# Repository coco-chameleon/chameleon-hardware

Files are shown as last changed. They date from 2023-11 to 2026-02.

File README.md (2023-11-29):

# CoCo Chameleon

The CoCo Chameleon is a cartridge for the Tandy TRS-80 Color Computer
line of home computers from the 1980s which emulates other cartridges.
It supports all three versions of the CoCo and should be able to
replicate the computer-facing behavior of nearly any other cartridge.

The primary aim of the project is to emulate ROM cartridges and all
of the common floppy and hard disk controller cartridges from image
files stored on a MicroSD card.

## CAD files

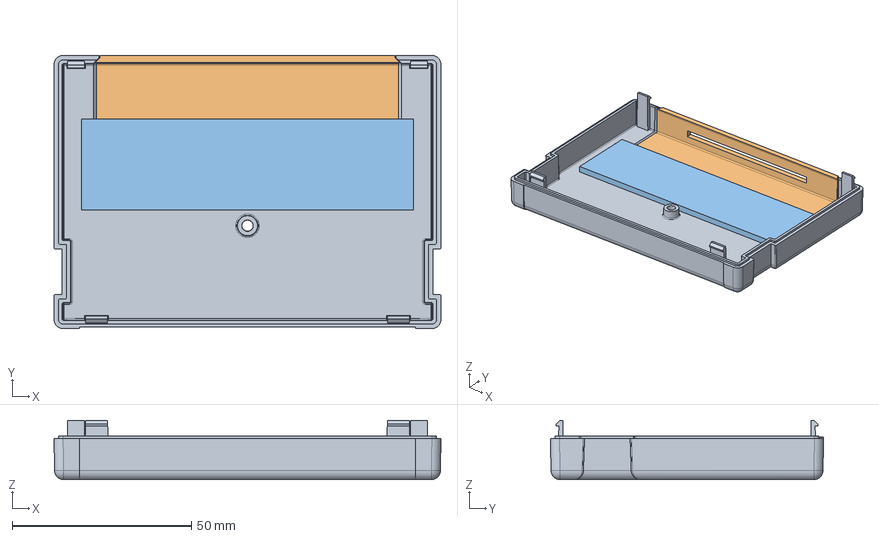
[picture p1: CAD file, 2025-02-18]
enclosure/ChameleonCase.FCStd
107.9 x 76.2 x 16.5 mm
P021_BottomShell
P022_Shutter
P023_ShutterBridge

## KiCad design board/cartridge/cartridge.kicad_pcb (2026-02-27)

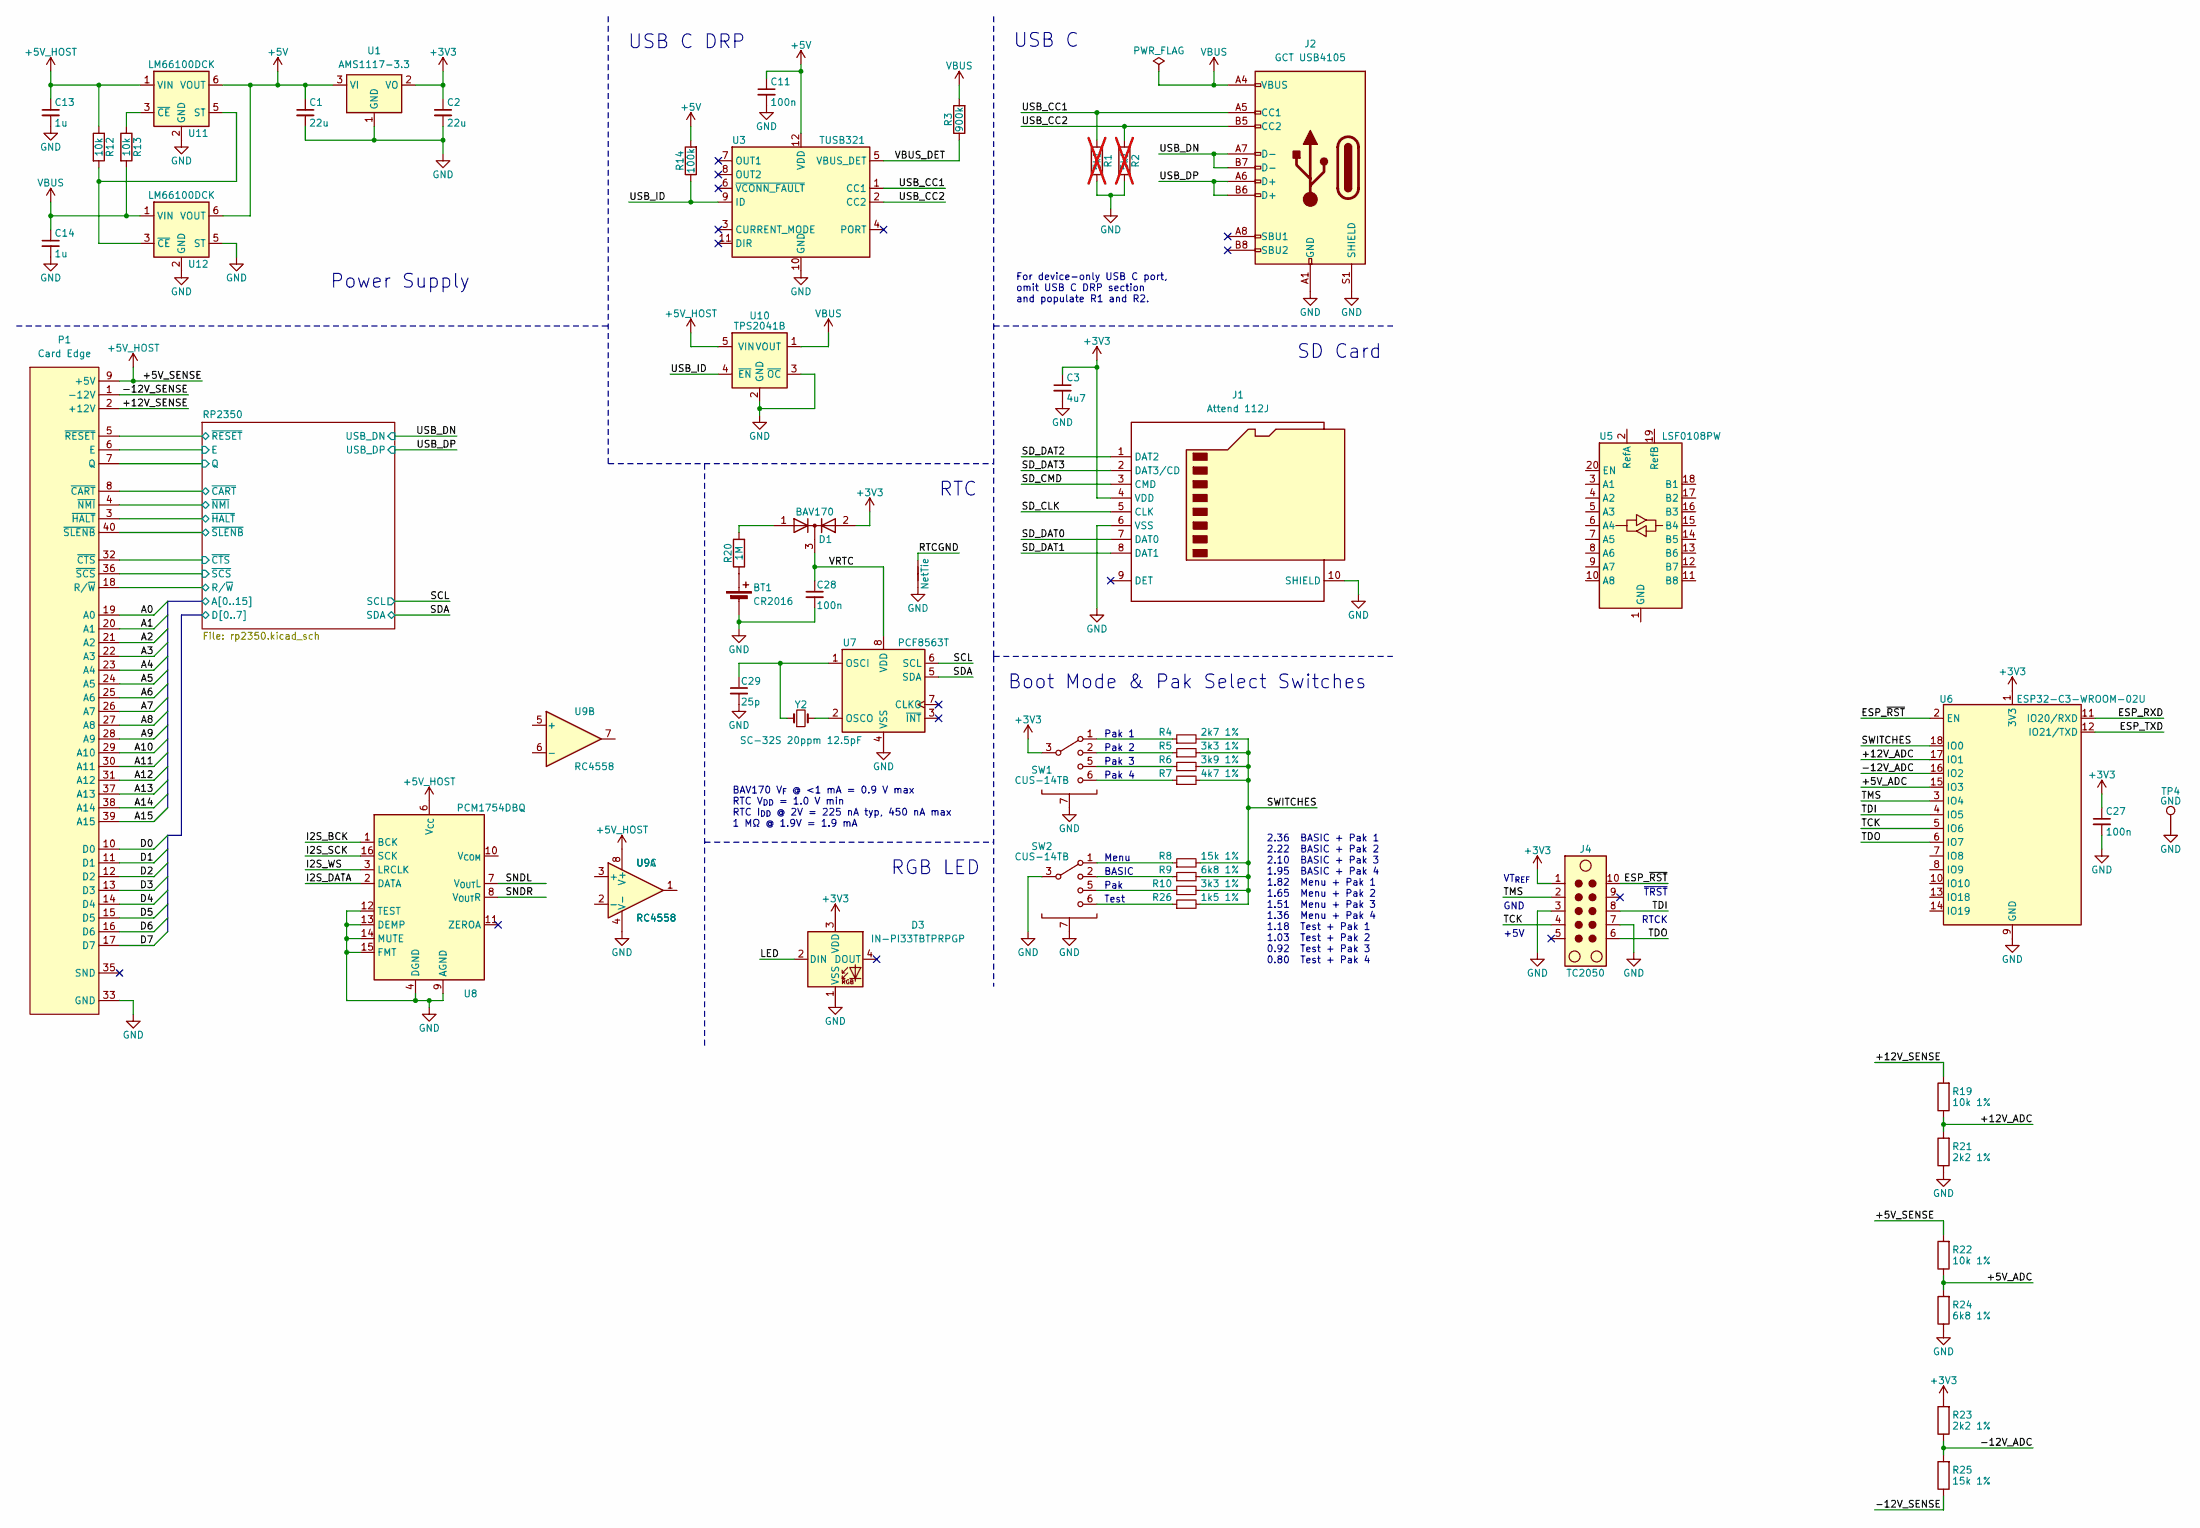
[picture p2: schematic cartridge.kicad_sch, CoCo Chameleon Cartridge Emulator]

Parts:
BT1: CR2016; BatteryHolder_Keystone_3026_1x2016
C1, C2: 22u; C_1206_3216Metric
C3: 4u7; C_0603_1608Metric
C11, C27, C28: 100n; C_0603_1608Metric
C13, C14: 1u; C_0603_1608Metric
C29: 25p; C_0603_1608Metric
D1: BAV170; SOT-23; LCSC C109309
D3: IN-PI33TBTPRPGP; LED_1414_3535Metric; LCSC C5259062
J1: Attend 112J; Attend_112J; LCSC C393941
J2: GCT USB4105; GCT_USB4105; LCSC C2894898
J4: TC2050; Tag-Connect_TC2050-IDC-NL_2x05_P1.27mm_Vertical
NT1: NetTie
P1: Card Edge; CoCo_Cart
R1, R2: 5k1; R_0603_1608Metric; not fitted
R3: 900k; R_0603_1608Metric
R4: 2k7 1%; R_0402_1005Metric
R5, R10: 3k3 1%; R_0402_1005Metric
R6: 3k9 1%; R_0402_1005Metric
R7: 4k7 1%; R_0402_1005Metric
R8, R25: 15k 1%; R_0402_1005Metric
R9, R24: 6k8 1%; R_0402_1005Metric
R12, R13: 10k; R_0603_1608Metric
R14: 100k; R_0603_1608Metric
R19, R22: 10k 1%; R_0402_1005Metric
R20: 1M; R_0603_1608Metric
R21, R23: 2k2 1%; R_0402_1005Metric
R26: 1k5 1%; R_0402_1005Metric
SW1, SW2: CUS-14TB; Nidec_CUS-14TB; LCSC C145846
TP4: GND; TestPoint_Pad_4.0x4.0mm
U1: AMS1117-3.3; SOT-223-3_TabPin2; LCSC C6186
U3: TUSB321; Texas_X2QFN-12_1.6x1.6mm_P0.4mm; LCSC C139392
U5: LSF0108PW; TSSOP-20_4.4x6.5mm_P0.65mm; LCSC C190219
U6: ESP32-C3-WROOM-02U
U7: PCF8563T; SOIC-8_3.9x4.9mm_P1.27mm; LCSC C7440
U8: PCM1754DBQ; SSOP-16_3.9x4.9mm_P0.635mm
U9: RC4558; SOIC-8_3.9x4.9mm_P1.27mm
U10: TPS2041B; SOT-23-5; LCSC C51386
U11, U12: LM66100DCK; SOT-363_SC-70-6; LCSC C2869734
Y2: SC-32S 20ppm 12.5pF; Crystal_SMD_3215-2Pin_3.2x1.5mm; LCSC C97606

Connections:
+3V3: C2.1, C3.1, C27.1, D1.2 (A), D3.3 (VDD), J1.4 (VDD), J4.1, R23.2, SW1.3 (COM), SW1.4 (COM), U1.2 (VO), U6.1 (3V3); also elsewhere on the board
+5V: C1.1, C11.1, R14.2, U1.3 (VI), U3.12 (VDD), U11.6 (VOUT), U12.6 (VOUT)
+5V_HOST: C13.1, P1.9 (+5V), R12.1, R22.2, U8.6 (V_{CC}), U9.8 (V+), U10.5 (VIN), U11.1 (VIN)
/+5V_ADC: R22.1, R24.2, U6.15 (IO3)
/+12V_ADC: R19.1, R21.2, U6.17 (IO1)
/+12V_SENSE: P1.2 (+12V), R19.2
/-12V_ADC: R23.1, R25.2, U6.16 (IO2)
/-12V_SENSE: P1.1 (-12V), R25.1
/ESP_RXD: U6.11 (IO20/RXD)
/ESP_TXD: U6.12 (IO21/TXD)
/ESP_~RST: J4.10, U6.2 (EN)
/I2S_BCK: U8.1 (BCK)
/I2S_DATA: U8.2 (DATA)
/I2S_SCK: U8.16 (SCK)
/I2S_WS: U8.3 (LRCLK)
/LED: D3.2 (DIN)
/RP2350/A0: P1.19 (A0); also elsewhere on the board
/RP2350/A1: P1.20 (A1); also elsewhere on the board
/RP2350/A2: P1.21 (A2); also elsewhere on the board
/RP2350/A3: P1.22 (A3); also elsewhere on the board
/RP2350/A4: P1.23 (A4); also elsewhere on the board
/RP2350/A5: P1.24 (A5); also elsewhere on the board
/RP2350/A6: P1.25 (A6); also elsewhere on the board
/RP2350/A7: P1.26 (A7); also elsewhere on the board
/RP2350/A8: P1.27 (A8); also elsewhere on the board
/RP2350/A9: P1.28 (A9); also elsewhere on the board
/RP2350/A10: P1.29 (A10); also elsewhere on the board
/RP2350/A11: P1.30 (A11); also elsewhere on the board
/RP2350/A12: P1.31 (A12); also elsewhere on the board
/RP2350/A13: P1.37 (A13); also elsewhere on the board
/RP2350/A14: P1.38 (A14); also elsewhere on the board
/RP2350/A15: P1.39 (A15); also elsewhere on the board
/RP2350/D0: P1.10 (D0); also elsewhere on the board
/RP2350/D1: P1.11 (D1); also elsewhere on the board
/RP2350/D2: P1.12 (D2); also elsewhere on the board
/RP2350/D3: P1.13 (D3); also elsewhere on the board
/RP2350/D4: P1.14 (D4); also elsewhere on the board
/RP2350/D5: P1.15 (D5); also elsewhere on the board
/RP2350/D6: P1.16 (D6); also elsewhere on the board
/RP2350/D7: P1.17 (D7); also elsewhere on the board
/RP2350/E: P1.6 (E); also elsewhere on the board
/RP2350/Q: P1.7 (Q); also elsewhere on the board
/RP2350/R/~W: P1.18 (R/~W); also elsewhere on the board
/RP2350/~CART: P1.8 (~CART); also elsewhere on the board
/RP2350/~CTS: P1.32 (~CTS); also elsewhere on the board
/RP2350/~HALT: P1.3 (~HALT); also elsewhere on the board
/RP2350/~NMI: P1.4 (~NMI); also elsewhere on the board
/RP2350/~RESET: P1.5 (~RESET); also elsewhere on the board
/RP2350/~SCS: P1.36 (~SCS); also elsewhere on the board
/RP2350/~SLENB: P1.40 (~SLENB); also elsewhere on the board
/SCL: U7.6 (SCL); also elsewhere on the board
/SDA: U7.5 (SDA); also elsewhere on the board
/SD_CLK: J1.5 (CLK)
/SD_CMD: J1.3 (CMD)
/SD_DAT0: J1.7 (DAT0)
/SD_DAT1: J1.8 (DAT1)
/SD_DAT2: J1.1 (DAT2)
/SD_DAT3: J1.2 (DAT3/CD)
/SNDL: U8.7 (V_{OUT}L)
/SNDR: U8.8 (V_{OUT}R)
/SWITCHES: R4.2, R5.2, R6.2, R7.2, R8.2, R9.2, R10.2, R26.2, U6.18 (IO0)
/TCK: J4.4, U6.5 (IO6)
/TDI: J4.8, U6.4 (IO5)
/TDO: J4.6, U6.6 (IO7)
/TMS: J4.2, U6.3 (IO4)
/USB_CC1: J2.A5 (CC1), R1.1, U3.1 (CC1)
/USB_CC2: J2.B5 (CC2), R2.1, U3.2 (CC2)
/USB_DN: J2.A7 (D-), J2.B7 (D-); also elsewhere on the board
/USB_DP: J2.A6 (D+), J2.B6 (D+); also elsewhere on the board
/USB_ID: R14.1, U3.9 (ID), U10.4 (~EN)
/VBUS_DET: R3.1, U3.5 (VBUS_DET)
/VRTC: C28.1, D1.3 (K), U7.8 (VDD)
GND: BT1.2 (-), C1.2, C2.2, C3.2, C11.2, C13.2, C14.2, C27.2, C28.2, C29.2, D3.1 (VSS), J1.6 (VSS), J1.10 (SHIELD), J2.A1 (GND), J2.A12 (GND), J2.B1 (GND), J2.B12 (GND), J2.S1 (SHIELD), J4.3, J4.7, NT1.1, P1.33 (GND), P1.34 (GND), R1.2, R2.2, R21.1, R24.1, SW1.7 (SHIELD), SW2.3 (COM), SW2.4 (COM), SW2.7 (SHIELD), TP4.1, U1.1 (GND), U3.10 (GND), U6.9 (GND), U6.19 (GND), U7.4 (VSS), U8.4 (DGND), U8.9 (AGND), U8.12 (TEST), U8.13 (DEMP), U8.14 (MUTE), U8.15 (FMT), U9.4 (V-), U10.2 (GND), U10.3 (~OC), U11.2 (GND), U12.2 (GND), U12.5 (ST); also elsewhere on the board
unnamed: BT1.1 (+), R20.1
unnamed: D1.1 (A), R20.2
unnamed: R4.1, SW1.1
unnamed: R5.1, SW1.2
unnamed: R8.1, SW2.1
unnamed: R9.1, SW2.2
unnamed: R6.1, SW1.5 (3)
unnamed: R7.1, SW1.6 (4)
unnamed: R10.1, SW2.5 (3)
unnamed: R26.1, SW2.6 (4)
unnamed: C29.1, U7.1 (OSCI), Y2.1
unnamed: U7.2 (OSCO), Y2.2
unnamed: R12.2, U11.5 (ST), U12.3 (~CE)
unnamed: R13.1, U11.3 (~CE)
VBUS: C14.1, J2.A4 (VBUS), J2.A9 (VBUS), J2.B4 (VBUS), J2.B9 (VBUS), R3.2, R13.2, U10.1 (VOUT), U12.1 (VIN)

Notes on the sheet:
SD Card
For device-only USB C port, omit USB C DRP section and populate R1 and R2.
Pak
Pak 3
BASIC
RTC
RTCK
2.36 BASIC + Pak 1 2.22 BASIC + Pak 2 2.10 BASIC + Pak 3 1.95 BASIC + Pak 4 1.82 Menu + Pak 1 1.65 Menu + Pak 2 1.51 Menu + Pak 3 1.36 Menu + Pak 4 1.18 Test + Pak 1 1.03 Test + Pak 2 0.92 Test + Pak 3 0.80 Test + Pak 4
Boot Mode & Pak Select Switches
VT_{REF}
+5V
Power Supply
BAV170 V_{F} @ <1 mA = 0.9 V max RTC V_{DD} = 1.0 V min RTC I_{DD} @ 2V = 225 nA typ, 450 nA max 1 MΩ @ 1.9V = 1.9 mA
USB C DRP
Test
~{TRST}
GND
Pak 4
Pak 1
RGB LED
Menu
Pak 2
USB C

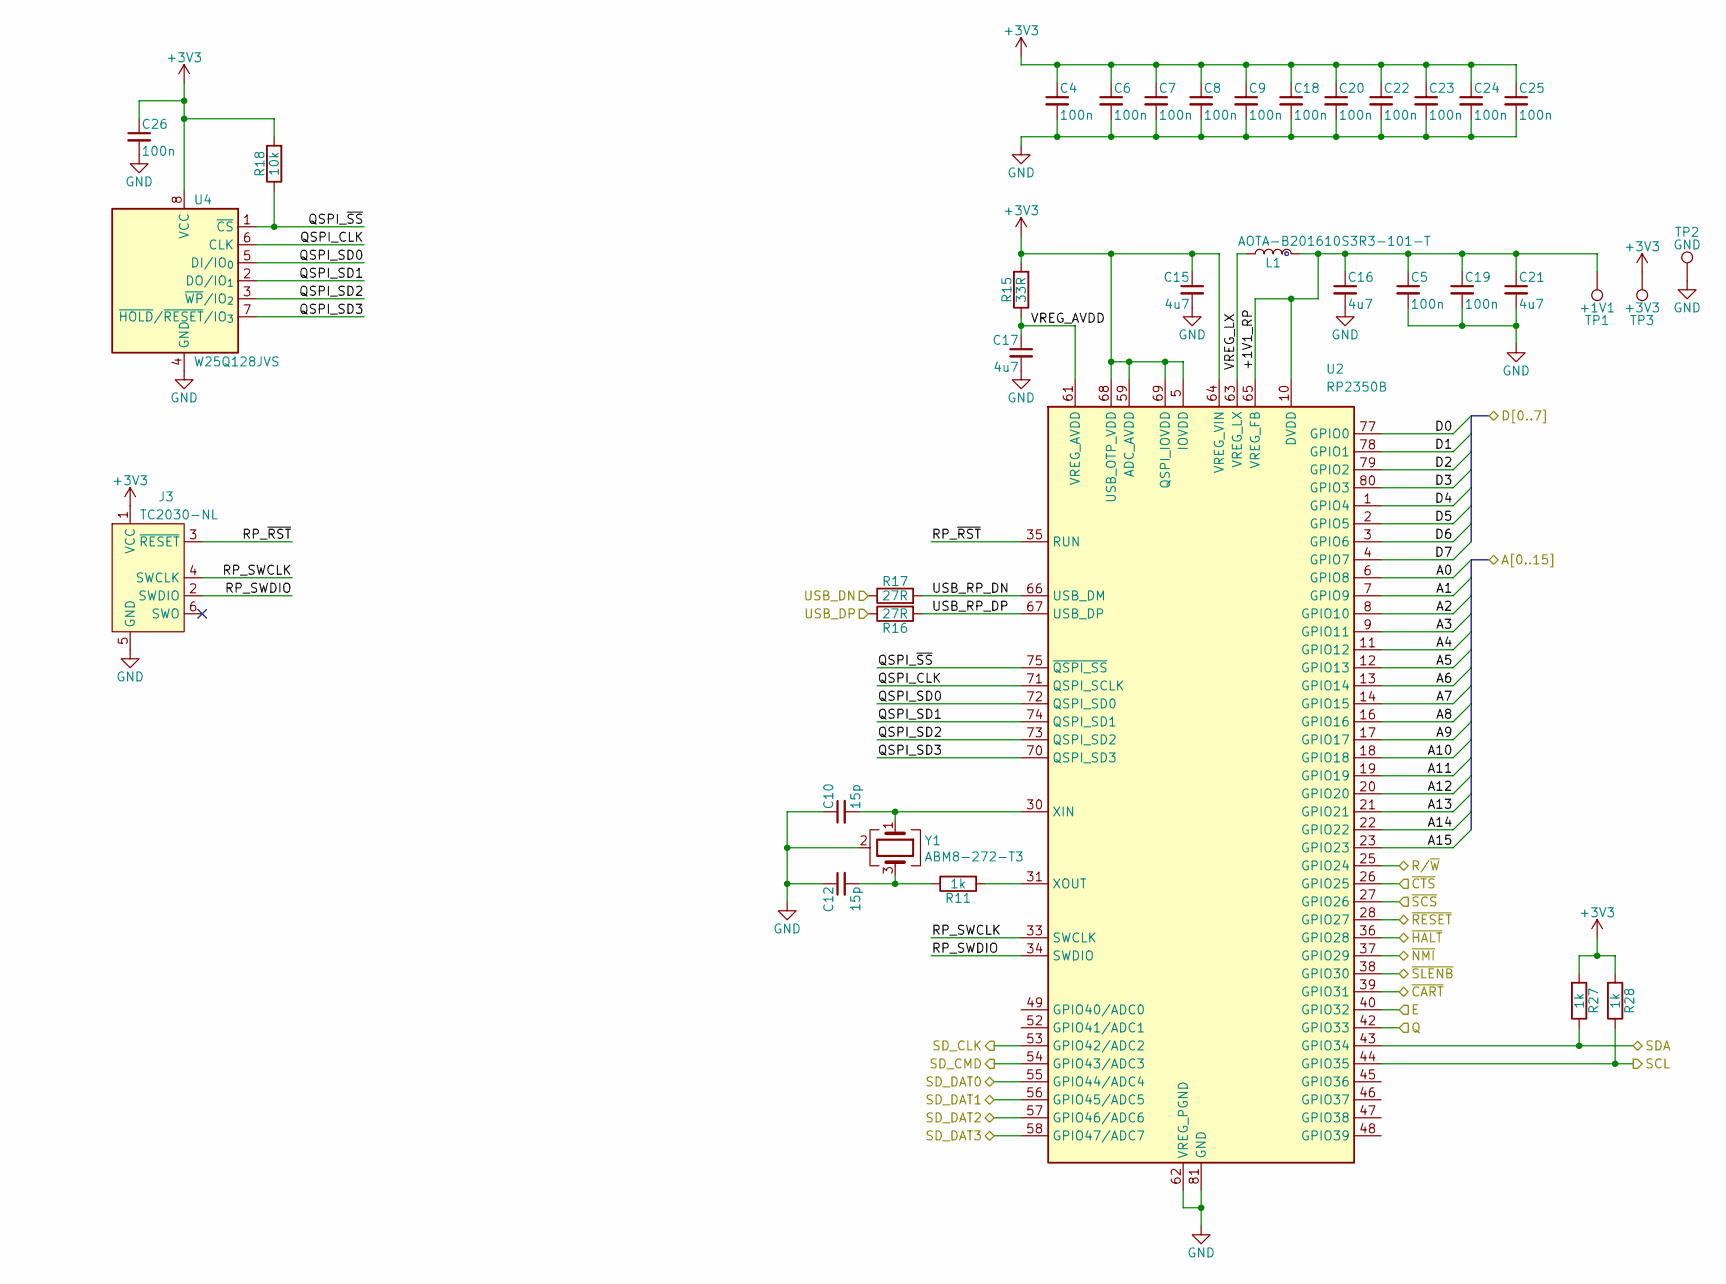
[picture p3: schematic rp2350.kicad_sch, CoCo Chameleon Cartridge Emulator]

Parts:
C4, C5, C6, C7, C8, C9, C18, C19, C20, C22, C23, C24, C25, C26: 100n; C_0402_1005Metric
C10, C12: 15p; C_0402_1005Metric
C15, C16: 4u7; C_0402_1005Metric_Pad0.53x0.47mm_Passthrough
C17, C21: 4u7; C_0402_1005Metric
J3: TC2030-NL; Tag-Connect_TC2030-IDC-NL_2x03_P1.27mm_Vertical
L1: AOTA-B201610S3R3-101-T; L_Polarized_2016; LCSC C42411119
R11, R27, R28: 1k; R_0402_1005Metric
R15: 33R; R_0402_1005Metric
R16, R17: 27R; R_0402_1005Metric
R18: 10k; R_0402_1005Metric
TP1: +1V1; TestPoint_Pad_D2.0mm
TP2: GND; TestPoint_Pad_4.0x4.0mm
TP3: +3V3; TestPoint_Pad_D2.0mm
U2: RP2350B; RP2350-QFN-80-1EP_10x10_P0.4mm_EP3.4x3.4mm_ThermalVias; LCSC C42415655
U4: W25Q128JVS; SOIC-8_3.9-5.3x5.3mm_P1.27mm
Y1: ABM8-272-T3; Crystal_SMD_3225-4Pin_3.2x2.5mm; LCSC C20625731

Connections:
+3V3: C4.1, C6.1, C7.1, C8.1, C9.1, C15.1, C18.1, C20.1, C22.1, C23.1, C24.1, C25.1, C26.1, J3.1 (VCC), R15.2, R18.2, R27.2, R28.2, TP3.1, U2.5 (IOVDD), U2.15 (IOVDD), U2.24 (IOVDD), U2.29 (IOVDD), U2.41 (IOVDD), U2.50 (IOVDD), U2.59 (ADC_AVDD), U2.60 (IOVDD), U2.64 (VREG_VIN), U2.68 (USB_OTP_VDD), U2.69 (QSPI_IOVDD), U2.76 (IOVDD), U4.8 (VCC); also elsewhere on the board
/RP2350/+1V1_RP: C5.1, C16.1, C19.1, C21.1, L1.1, TP1.1, U2.10 (DVDD), U2.32 (DVDD), U2.51 (DVDD), U2.65 (VREG_FB)
/RP2350/A0: U2.6 (GPIO8); also elsewhere on the board
/RP2350/A1: U2.7 (GPIO9); also elsewhere on the board
/RP2350/A2: U2.8 (GPIO10); also elsewhere on the board
/RP2350/A3: U2.9 (GPIO11); also elsewhere on the board
/RP2350/A4: U2.11 (GPIO12); also elsewhere on the board
/RP2350/A5: U2.12 (GPIO13); also elsewhere on the board
/RP2350/A6: U2.13 (GPIO14); also elsewhere on the board
/RP2350/A7: U2.14 (GPIO15); also elsewhere on the board
/RP2350/A8: U2.16 (GPIO16); also elsewhere on the board
/RP2350/A9: U2.17 (GPIO17); also elsewhere on the board
/RP2350/A10: U2.18 (GPIO18); also elsewhere on the board
/RP2350/A11: U2.19 (GPIO19); also elsewhere on the board
/RP2350/A12: U2.20 (GPIO20); also elsewhere on the board
/RP2350/A13: U2.21 (GPIO21); also elsewhere on the board
/RP2350/A14: U2.22 (GPIO22); also elsewhere on the board
/RP2350/A15: U2.23 (GPIO23); also elsewhere on the board
/RP2350/D0: U2.77 (GPIO0); also elsewhere on the board
/RP2350/D1: U2.78 (GPIO1); also elsewhere on the board
/RP2350/D2: U2.79 (GPIO2); also elsewhere on the board
/RP2350/D3: U2.80 (GPIO3); also elsewhere on the board
/RP2350/D4: U2.1 (GPIO4); also elsewhere on the board
/RP2350/D5: U2.2 (GPIO5); also elsewhere on the board
/RP2350/D6: U2.3 (GPIO6); also elsewhere on the board
/RP2350/D7: U2.4 (GPIO7); also elsewhere on the board
/RP2350/E: U2.40 (GPIO32); also elsewhere on the board
/RP2350/Q: U2.42 (GPIO33); also elsewhere on the board
/RP2350/QSPI_CLK: U2.71 (QSPI_SCLK), U4.6 (CLK)
/RP2350/QSPI_SD0: U2.72 (QSPI_SD0), U4.5 (DI/IO_{0})
/RP2350/QSPI_SD1: U2.74 (QSPI_SD1), U4.2 (DO/IO_{1})
/RP2350/QSPI_SD2: U2.73 (QSPI_SD2), U4.3 (~WP/IO_{2})
/RP2350/QSPI_SD3: U2.70 (QSPI_SD3), U4.7 (~HOLD/~RESET/IO_{3})
/RP2350/QSPI_~SS: R18.1, U2.75 (~QSPI_SS), U4.1 (~CS)
/RP2350/RP_SWCLK: J3.4 (SWCLK), U2.33 (SWCLK)
/RP2350/RP_SWDIO: J3.2 (SWDIO), U2.34 (SWDIO)
/RP2350/RP_~RST: J3.3 (~RESET), U2.35 (RUN)
/RP2350/R/~W: U2.25 (GPIO24); also elsewhere on the board
/RP2350/SD_CLK: U2.53 (GPIO42/ADC2)
/RP2350/SD_CMD: U2.54 (GPIO43/ADC3)
/RP2350/SD_DAT0: U2.55 (GPIO44/ADC4)
/RP2350/SD_DAT1: U2.56 (GPIO45/ADC5)
/RP2350/SD_DAT2: U2.57 (GPIO46/ADC6)
/RP2350/SD_DAT3: U2.58 (GPIO47/ADC7)
/RP2350/USB_RP_DN: R17.2, U2.66 (USB_DM)
/RP2350/USB_RP_DP: R16.2, U2.67 (USB_DP)
/RP2350/VREG_AVDD: C17.1, R15.1, U2.61 (VREG_AVDD)
/RP2350/VREG_LX: L1.2, U2.63 (VREG_LX)
/RP2350/~CART: U2.39 (GPIO31); also elsewhere on the board
/RP2350/~CTS: U2.26 (GPIO25); also elsewhere on the board
/RP2350/~HALT: U2.36 (GPIO28); also elsewhere on the board
/RP2350/~NMI: U2.37 (GPIO29); also elsewhere on the board
/RP2350/~RESET: U2.28 (GPIO27); also elsewhere on the board
/RP2350/~SCS: U2.27 (GPIO26); also elsewhere on the board
/RP2350/~SLENB: U2.38 (GPIO30); also elsewhere on the board
/SCL: R28.1, U2.44 (GPIO35); also elsewhere on the board
/SDA: R27.1, U2.43 (GPIO34); also elsewhere on the board
/USB_DN: R17.1; also elsewhere on the board
/USB_DP: R16.1; also elsewhere on the board
GND: C4.2, C5.2, C6.2, C7.2, C8.2, C9.2, C10.1, C12.1, C15.2, C16.2, C17.2, C18.2, C19.2, C20.2, C21.2, C22.2, C23.2, C24.2, C25.2, C26.2, J3.5 (GND), TP2.1, U2.62 (VREG_PGND), U2.81 (GND), U4.4 (GND), Y1.2 (G), Y1.4 (G); also elsewhere on the board
unnamed: C12.2, R11.1, Y1.3
unnamed: C10.2, U2.30 (XIN), Y1.1
unnamed: R11.2, U2.31 (XOUT)

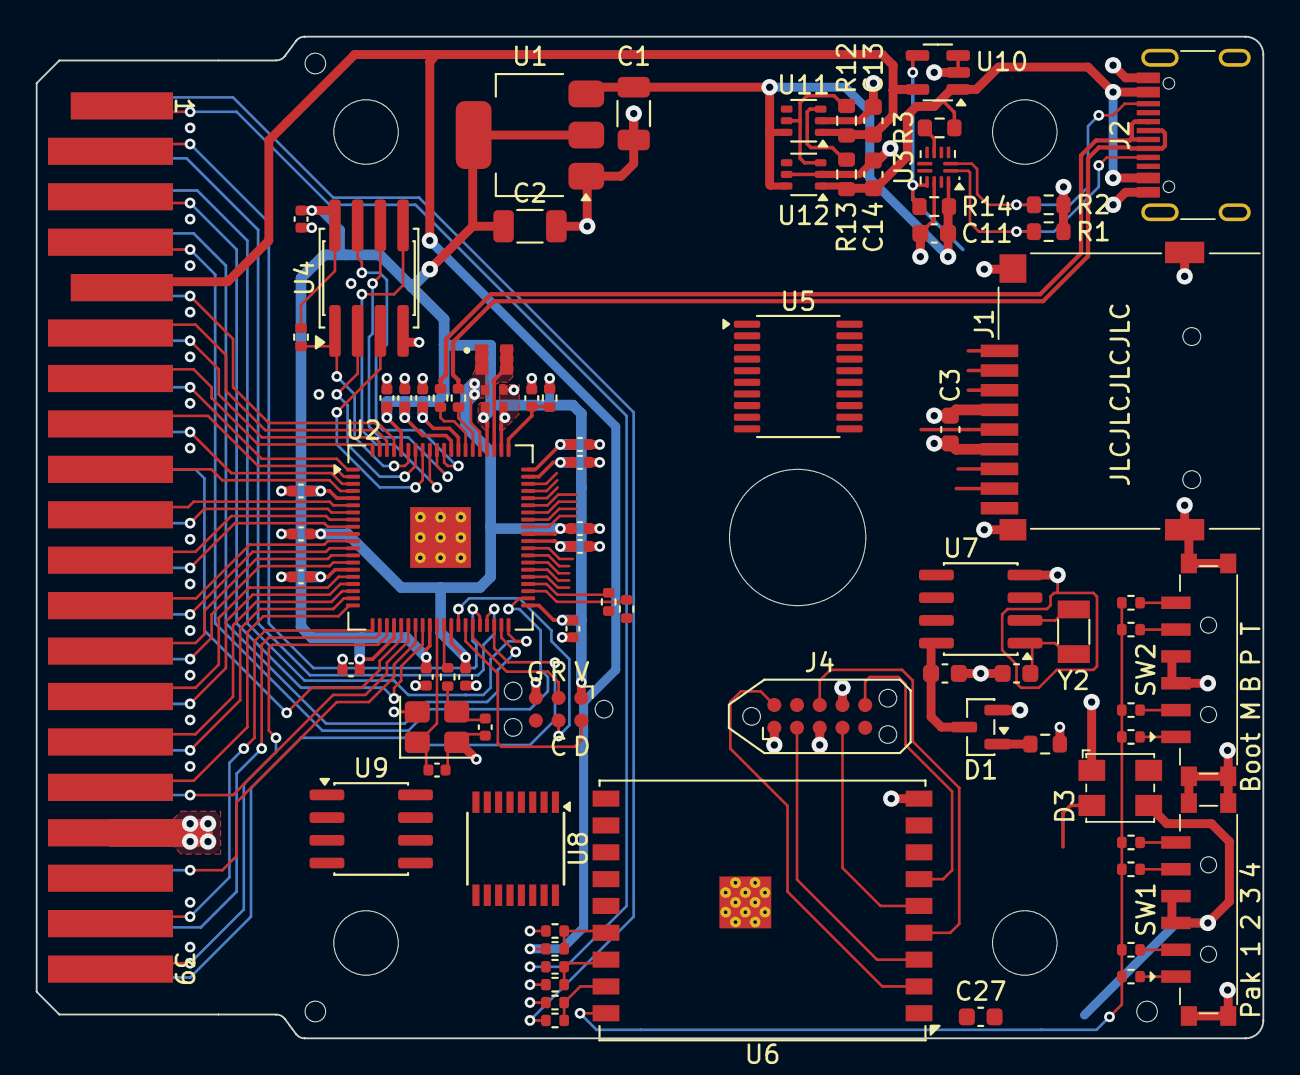
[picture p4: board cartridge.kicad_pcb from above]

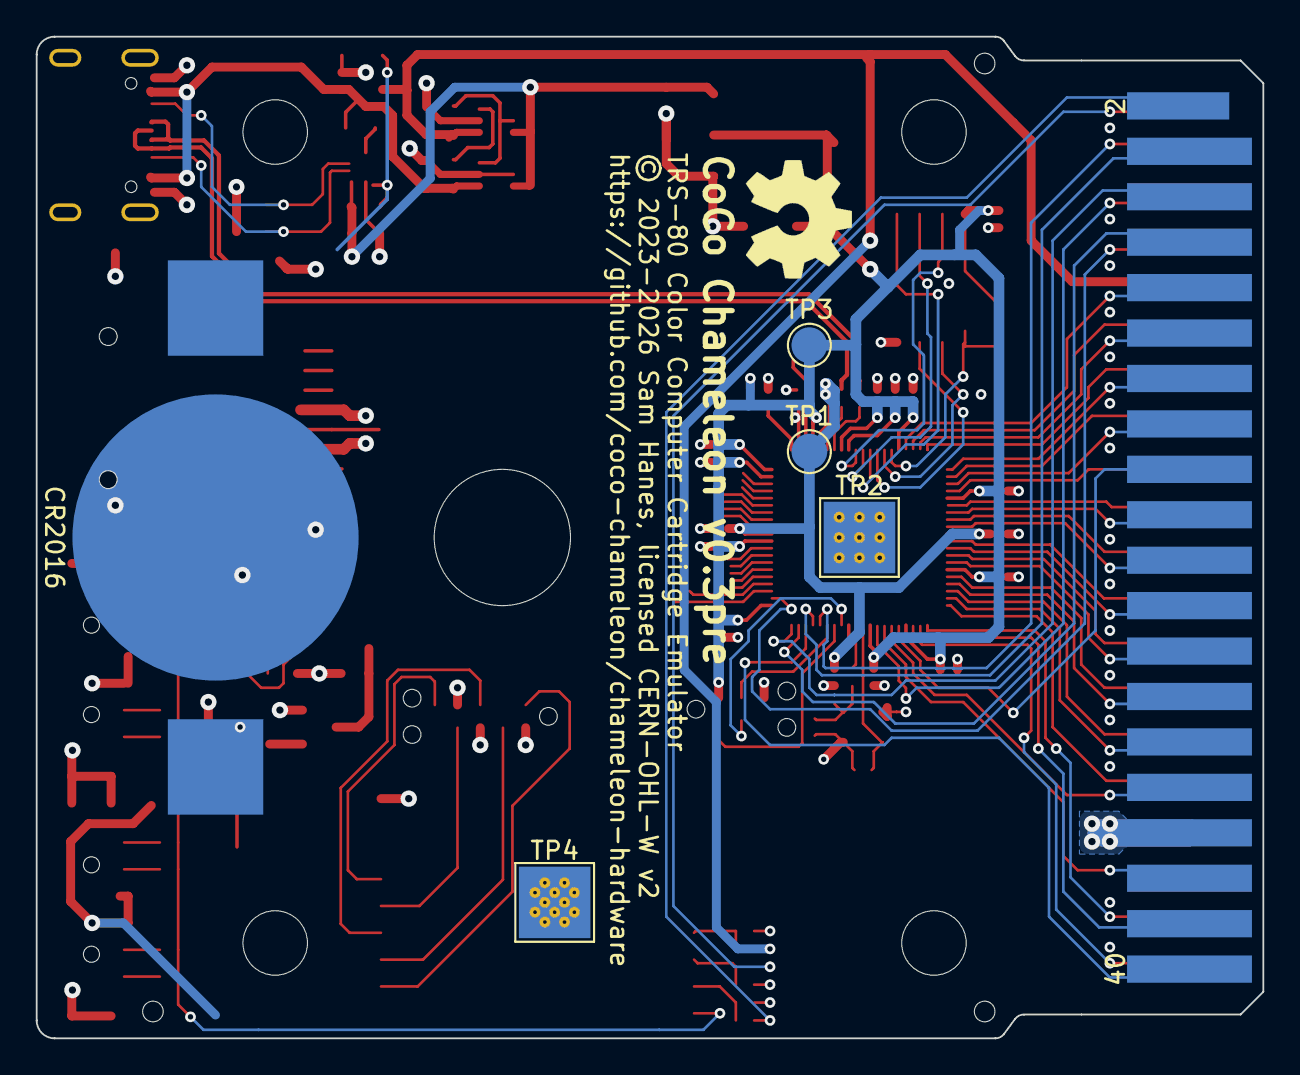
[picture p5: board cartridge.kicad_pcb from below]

Board: 4 copper layers, 68.6 x 56.0 mm, 92 parts (6 on the bottom side), 90 nets.

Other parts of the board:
G2: OSHW-Symbol_6.7x6mm_SilkScreen
MH1, MH1#2, MH1#3, MH2: CoCo_MountingHole
MH5: CoCo_ClearanceHole

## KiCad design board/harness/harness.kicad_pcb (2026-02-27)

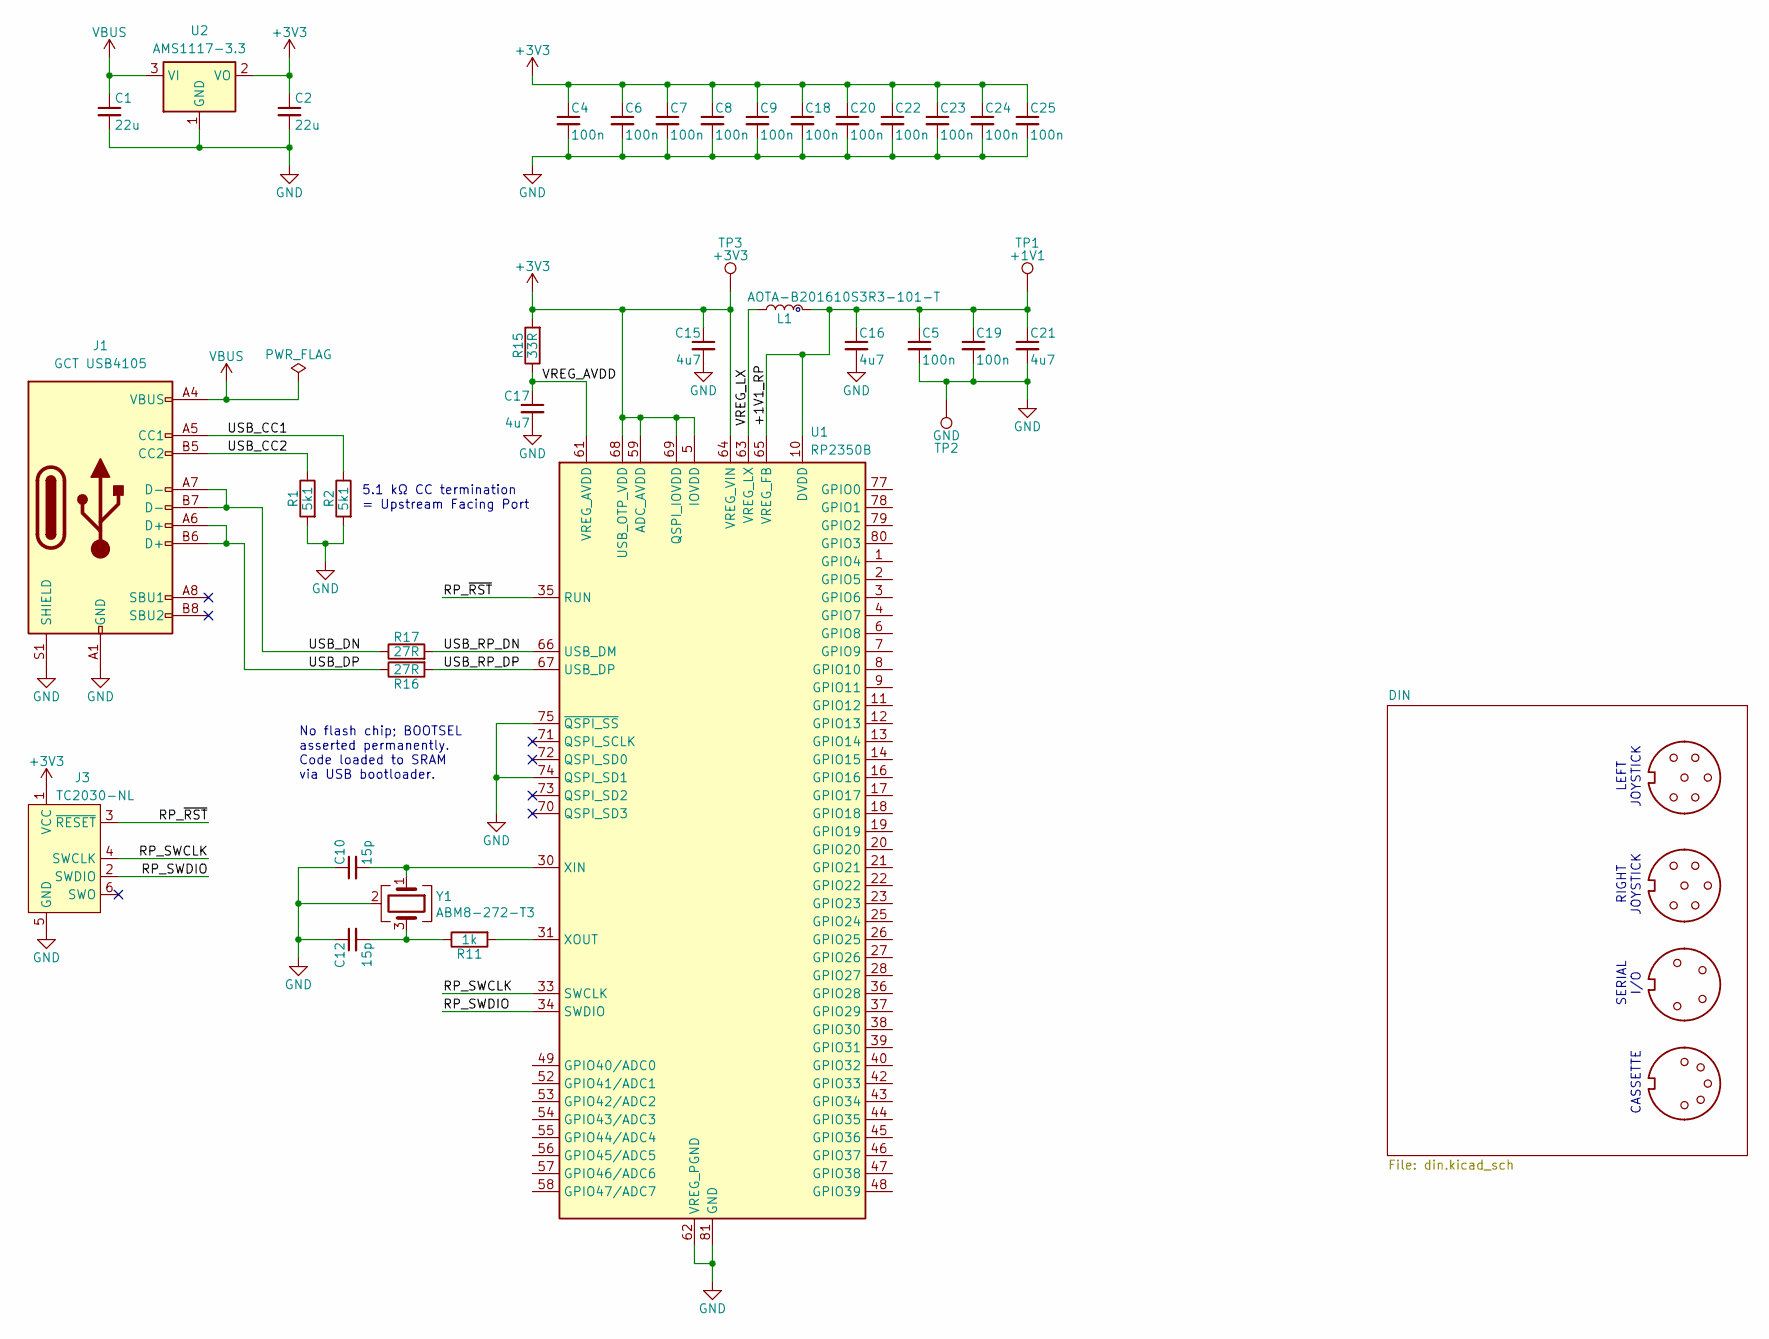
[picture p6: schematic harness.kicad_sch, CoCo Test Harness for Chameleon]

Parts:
C1, C2: 22u; C_1206_3216Metric
C4, C5, C6, C7, C8, C9, C18, C19, C20, C22, C23, C24, C25: 100n; C_0402_1005Metric
C10, C12: 15p; C_0402_1005Metric
C15, C16: 4u7; C_0402_1005Metric_Pad0.53x0.47mm_Passthrough
C17, C21: 4u7; C_0402_1005Metric
J1: GCT USB4105; GCT_USB4105; LCSC C2894898
J3: TC2030-NL; Tag-Connect_TC2030-IDC-NL_2x03_P1.27mm_Vertical
L1: AOTA-B201610S3R3-101-T; L_Polarized_2016; LCSC C42411119
R1, R2: 5k1; R_0402_1005Metric
R11: 1k; R_0402_1005Metric
R15: 33R; R_0402_1005Metric
R16, R17: 27R; R_0402_1005Metric
TP1: +1V1; TestPoint_Pad_D2.0mm
TP2: GND; TestPoint_Pad_4.0x4.0mm
TP3: +3V3; TestPoint_Pad_D2.0mm
U1: RP2350B; RP2350-QFN-80-1EP_10x10_P0.4mm_EP3.4x3.4mm_ThermalVias; LCSC C42415655
U2: AMS1117-3.3; SOT-223-3_TabPin2; LCSC C6186
Y1: ABM8-272-T3; Crystal_SMD_3225-4Pin_3.2x2.5mm; LCSC C20625731

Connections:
+3V3: C2.1, C4.1, C6.1, C7.1, C8.1, C9.1, C15.1, C18.1, C20.1, C22.1, C23.1, C24.1, C25.1, J3.1 (VCC), R15.2, TP3.1, U1.5 (IOVDD), U1.15 (IOVDD), U1.24 (IOVDD), U1.29 (IOVDD), U1.41 (IOVDD), U1.50 (IOVDD), U1.59 (ADC_AVDD), U1.60 (IOVDD), U1.64 (VREG_VIN), U1.68 (USB_OTP_VDD), U1.69 (QSPI_IOVDD), U1.76 (IOVDD), U2.2 (VO)
/+1V1_RP: C5.1, C16.1, C19.1, C21.1, L1.1, TP1.1, U1.10 (DVDD), U1.32 (DVDD), U1.51 (DVDD), U1.65 (VREG_FB)
/RP_SWCLK: J3.4 (SWCLK), U1.33 (SWCLK)
/RP_SWDIO: J3.2 (SWDIO), U1.34 (SWDIO)
/RP_~RST: J3.3 (~RESET), U1.35 (RUN)
/USB_CC1: J1.A5 (CC1), R2.1
/USB_CC2: J1.B5 (CC2), R1.1
/USB_DN: J1.A7 (D-), J1.B7 (D-), R17.1
/USB_DP: J1.A6 (D+), J1.B6 (D+), R16.1
/USB_RP_DN: R17.2, U1.66 (USB_DM)
/USB_RP_DP: R16.2, U1.67 (USB_DP)
/VREG_AVDD: C17.1, R15.1, U1.61 (VREG_AVDD)
/VREG_LX: L1.2, U1.63 (VREG_LX)
GND: C1.2, C2.2, C4.2, C5.2, C6.2, C7.2, C8.2, C9.2, C10.1, C12.1, C15.2, C16.2, C17.2, C18.2, C19.2, C20.2, C21.2, C22.2, C23.2, C24.2, C25.2, J1.A1 (GND), J1.A12 (GND), J1.B1 (GND), J1.B12 (GND), J1.S1 (SHIELD), J3.5 (GND), R1.2, R2.2, TP2.1, U1.62 (VREG_PGND), U1.74 (QSPI_SD1), U1.75 (~QSPI_SS), U1.81 (GND), U2.1 (GND), Y1.2 (G), Y1.4 (G)
unnamed: C12.2, R11.1, Y1.3
unnamed: C10.2, U1.30 (XIN), Y1.1
unnamed: R11.2, U1.31 (XOUT)
VBUS: C1.1, J1.A4 (VBUS), J1.A9 (VBUS), J1.B4 (VBUS), J1.B9 (VBUS), U2.3 (VI)

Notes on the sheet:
RIGHT JOYSTICK
No flash chip; BOOTSEL asserted permanently. Code loaded to SRAM via USB bootloader.
5.1 kΩ CC termination = Upstream Facing Port
CASSETTE
LEFT JOYSTICK
SERIAL I/O

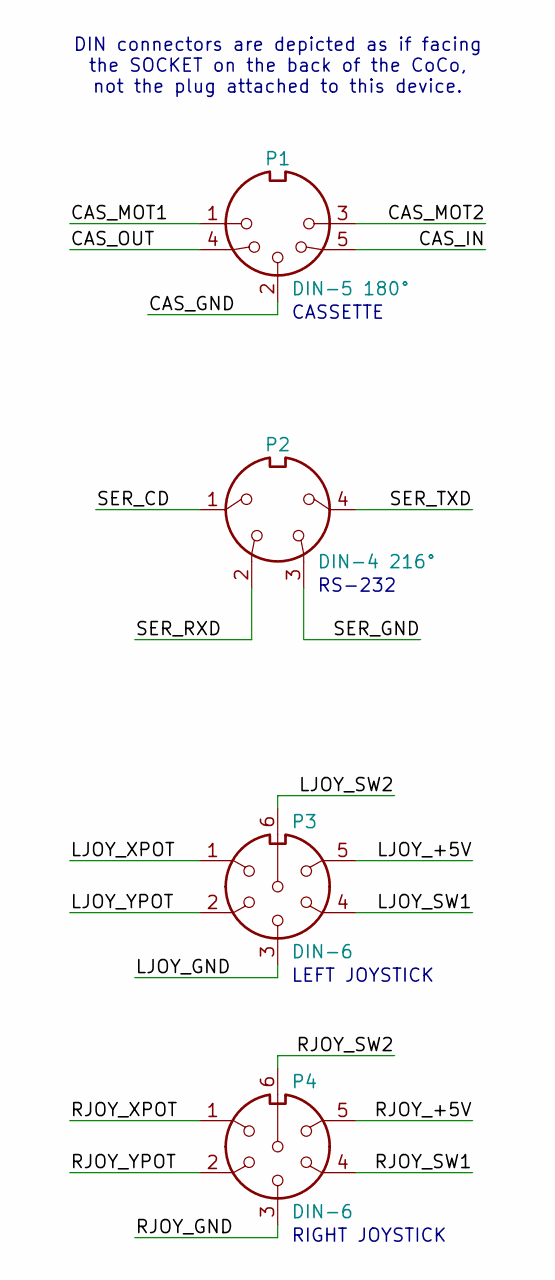
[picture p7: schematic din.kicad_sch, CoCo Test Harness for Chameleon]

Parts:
P1: DIN-5 180°; PinHeader_1x05_P2.00mm_Vertical
P2: DIN-4 216°; PinHeader_1x04_P2.00mm_Vertical
P3, P4: DIN-6; PinHeader_1x06_P2.00mm_Vertical

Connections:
/DIN/CAS_GND: P1.2
/DIN/CAS_IN: P1.5
/DIN/CAS_MOT1: P1.1
/DIN/CAS_MOT2: P1.3
/DIN/CAS_OUT: P1.4
/DIN/LJOY_+5V: P3.5
/DIN/LJOY_GND: P3.3
/DIN/LJOY_SW1: P3.4
/DIN/LJOY_SW2: P3.6
/DIN/LJOY_XPOT: P3.1
/DIN/LJOY_YPOT: P3.2
/DIN/RJOY_+5V: P4.5
/DIN/RJOY_GND: P4.3
/DIN/RJOY_SW1: P4.4
/DIN/RJOY_SW2: P4.6
/DIN/RJOY_XPOT: P4.1
/DIN/RJOY_YPOT: P4.2
/DIN/SER_CD: P2.1
/DIN/SER_GND: P2.3
/DIN/SER_RXD: P2.2
/DIN/SER_TXD: P2.4

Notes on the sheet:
LEFT JOYSTICK
DIN connectors are depicted as if facing the SOCKET on the back of the CoCo, not the plug attached to this device.
CASSETTE
RIGHT JOYSTICK
RS-232

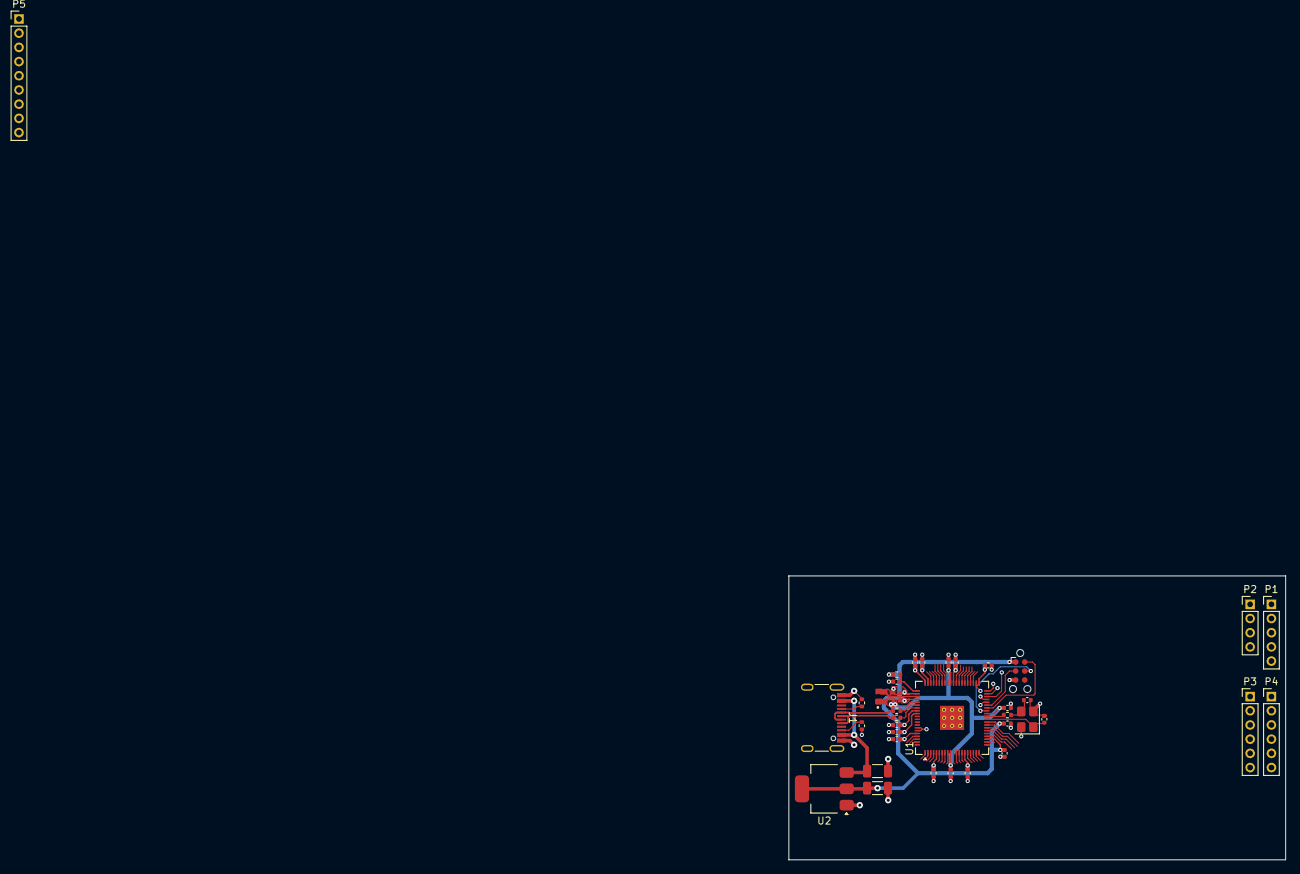
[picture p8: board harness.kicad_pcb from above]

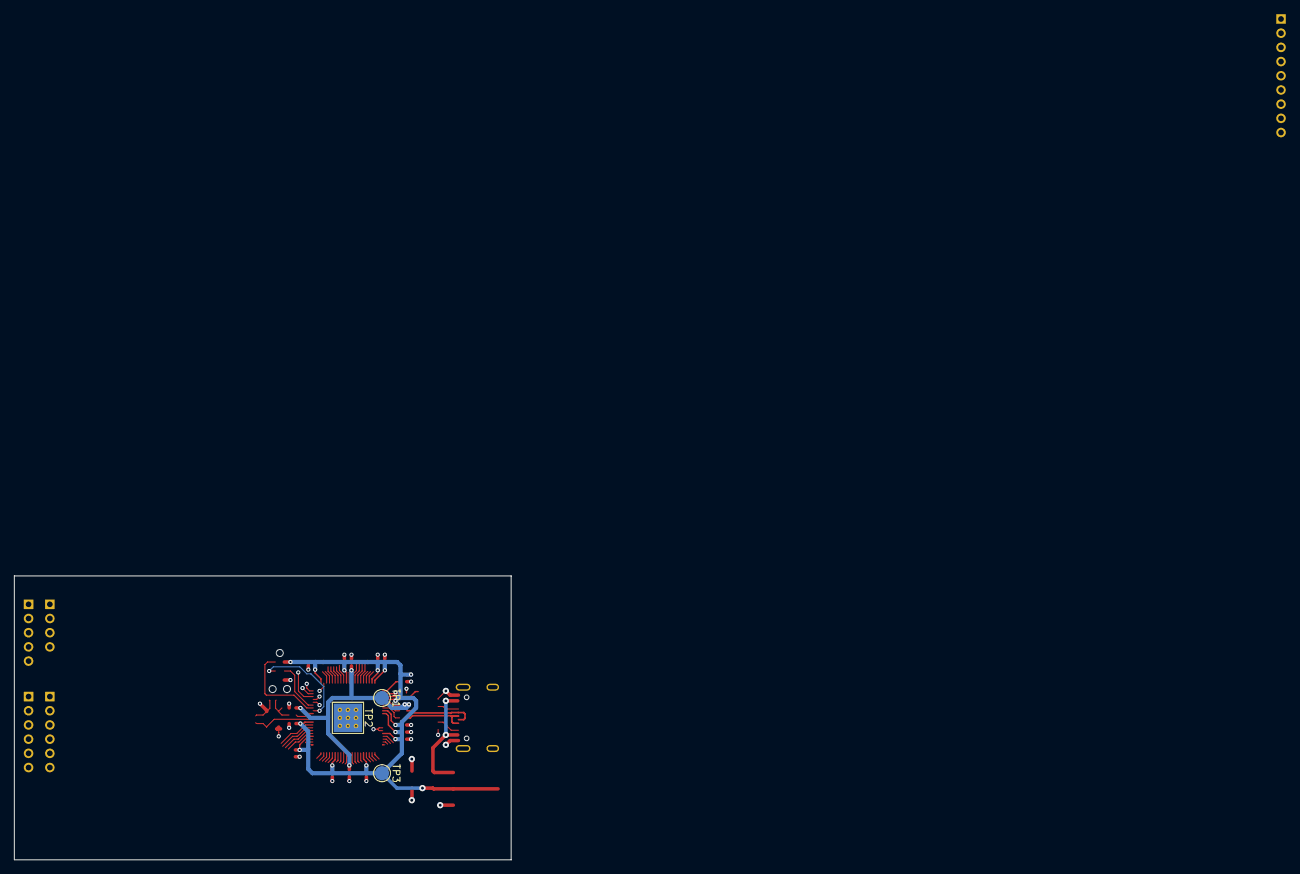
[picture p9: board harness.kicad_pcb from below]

Board: 4 copper layers, 70.0 x 40.0 mm, 41 parts (3 on the bottom side), 18 nets.

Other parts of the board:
P5: USB_C_Plug_USB2.0; PinHeader_1x09_P2.00mm_Vertical

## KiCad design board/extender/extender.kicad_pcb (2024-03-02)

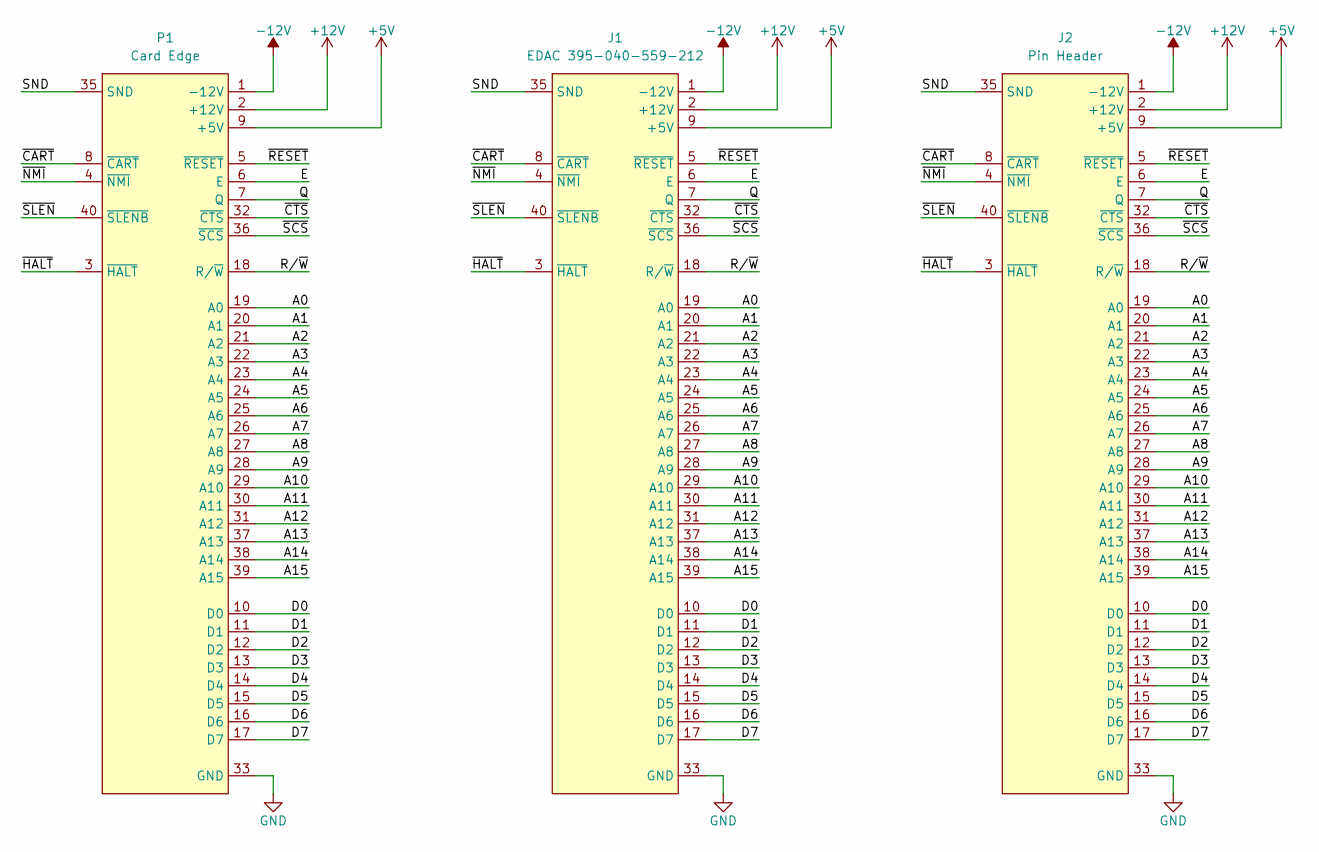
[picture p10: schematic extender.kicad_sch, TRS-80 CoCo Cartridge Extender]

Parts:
J1: EDAC 395-040-559-212; EDAC_395-040-559-212
J2: Pin Header; PinHeader_2x20_P2.54mm_Vertical
P1: Card Edge; CoCo_Cart

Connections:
+5V: J1.9 (+5V), J2.9 (+5V), P1.9 (+5V)
+12V: J1.2 (+12V), J2.2 (+12V), P1.2 (+12V)
-12V: J1.1 (-12V), J2.1 (-12V), P1.1 (-12V)
/A0: J1.19 (A0), J2.19 (A0), P1.19 (A0)
/A1: J1.20 (A1), J2.20 (A1), P1.20 (A1)
/A2: J1.21 (A2), J2.21 (A2), P1.21 (A2)
/A3: J1.22 (A3), J2.22 (A3), P1.22 (A3)
/A4: J1.23 (A4), J2.23 (A4), P1.23 (A4)
/A5: J1.24 (A5), J2.24 (A5), P1.24 (A5)
/A6: J1.25 (A6), J2.25 (A6), P1.25 (A6)
/A7: J1.26 (A7), J2.26 (A7), P1.26 (A7)
/A8: J1.27 (A8), J2.27 (A8), P1.27 (A8)
/A9: J1.28 (A9), J2.28 (A9), P1.28 (A9)
/A10: J1.29 (A10), J2.29 (A10), P1.29 (A10)
/A11: J1.30 (A11), J2.30 (A11), P1.30 (A11)
/A12: J1.31 (A12), J2.31 (A12), P1.31 (A12)
/A13: J1.37 (A13), J2.37 (A13), P1.37 (A13)
/A14: J1.38 (A14), J2.38 (A14), P1.38 (A14)
/A15: J1.39 (A15), J2.39 (A15), P1.39 (A15)
/D0: J1.10 (D0), J2.10 (D0), P1.10 (D0)
/D1: J1.11 (D1), J2.11 (D1), P1.11 (D1)
/D2: J1.12 (D2), J2.12 (D2), P1.12 (D2)
/D3: J1.13 (D3), J2.13 (D3), P1.13 (D3)
/D4: J1.14 (D4), J2.14 (D4), P1.14 (D4)
/D5: J1.15 (D5), J2.15 (D5), P1.15 (D5)
/D6: J1.16 (D6), J2.16 (D6), P1.16 (D6)
/D7: J1.17 (D7), J2.17 (D7), P1.17 (D7)
/E: J1.6 (E), J2.6 (E), P1.6 (E)
/Q: J1.7 (Q), J2.7 (Q), P1.7 (Q)
/R/~W: J1.18 (R/~W), J2.18 (R/~W), P1.18 (R/~W)
/SND: J1.35 (SND), J2.35 (SND), P1.35 (SND)
/~CART: J1.8 (~CART), J2.8 (~CART), P1.8 (~CART)
/~CTS: J1.32 (~CTS), J2.32 (~CTS), P1.32 (~CTS)
/~HALT: J1.3 (~HALT), J2.3 (~HALT), P1.3 (~HALT)
/~NMI: J1.4 (~NMI), J2.4 (~NMI), P1.4 (~NMI)
/~RESET: J1.5 (~RESET), J2.5 (~RESET), P1.5 (~RESET)
/~SCS: J1.36 (~SCS), J2.36 (~SCS), P1.36 (~SCS)
/~SLEN: J1.40 (~SLENB), J2.40 (~SLENB), P1.40 (~SLENB)
GND: J1.33 (GND), J1.34 (GND), J2.33 (GND), J2.34 (GND), P1.33 (GND), P1.34 (GND)

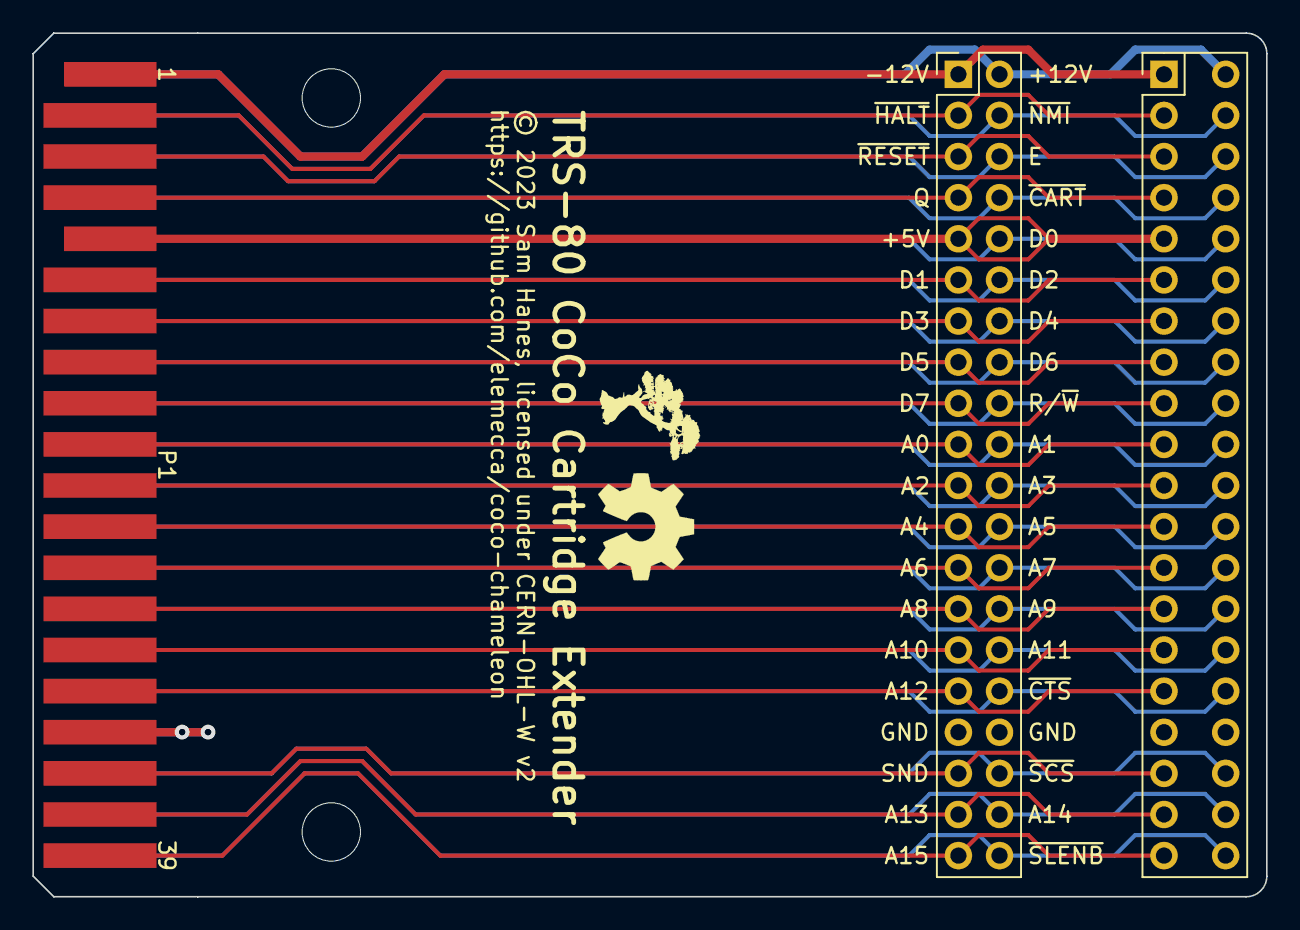
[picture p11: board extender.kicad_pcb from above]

Board: 4 copper layers, 76.2 x 53.3 mm, 5 parts (0 on the bottom side), 39 nets.

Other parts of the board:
MH1, MH2: CoCo_MountingHole

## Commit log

2023-11-28 Start with a partially-designed board.
    [coco-wedge.kicad_pcb, coco-wedge.kicad_sch]
2023-11-29 Add most of the audio system, do some routing.
    [coco-wedge.kicad_pcb, coco-wedge.kicad_sch]
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2023-11-29 Update schematic info block and add a README.
    [cartridge.kicad_pcb, cartridge.kicad_sch]
2023-11-30 Place and route MCU power and crystal.
    [cartridge.kicad_pcb, cartridge.kicad_sch]
2023-12-02 Choose parts for everything plus more routing.
    [cartridge.kicad_pcb, cartridge.kicad_sch]
2023-12-05 Update footprint positions to match JLCPCB.
    [cartridge.kicad_pcb]
2023-12-06 Rip up and try routing as 2 layer.
    [cartridge.kicad_pcb]
2023-12-06 Adjust layout based on an actual Tandy cartridge.
    [cartridge.kicad_pcb, cartridge.kicad_sch]
2023-12-07 Another attempt at routing.
    [cartridge.kicad_pcb, cartridge.kicad_sch]
2023-12-12 Move CoCo footprints up to project.
    [cartridge.kicad_pcb, cartridge.kicad_sch]
2023-12-13 Add cartridge extender board.
    [extender.kicad_pcb, extender.kicad_sch]
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2023-12-14 Update boot switches to support MultiPak.
    [cartridge.kicad_pcb, cartridge.kicad_sch]
2023-12-14 Add missing LCSC numbers.
    [cartridge.kicad_pcb, cartridge.kicad_sch]
2023-12-14 Add JLC tooling holes.
    [cartridge.kicad_pcb]
2023-12-15 Move pin assignments around to accomodate new switches.
    [cartridge.kicad_pcb, cartridge.kicad_sch]
2023-12-20 Switch to cheaper SD card socket, more routing.
    [cartridge.kicad_pcb, cartridge.kicad_sch]
2023-12-20 Fully route the card-edge connector.
    [cartridge.kicad_pcb]
2023-12-20 Route power for the main ICs.
    [cartridge.kicad_pcb, cartridge.kicad_sch]
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2023-12-22 Final cleanup for first cartridge prototype.
    [cartridge.kicad_pcb, cartridge.kicad_sch]
2023-12-22 Change extender board to 4-layer.
    [extender.kicad_pcb]
2024-03-02 Update KiCad projects to v8.
    [cartridge.kicad_pcb, cartridge.kicad_sch, extender.kicad_pcb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]
2024-03-03 Sketch out a redesign to use an RP2040.
    [cartridge.kicad_sch, host.kicad_sch]
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2024-05-18 Start updating board to use ESP32-S3.
    [cartridge.kicad_sch, host.kicad_sch]
2024-05-27 Design and mostly route level shifters.
    [cartridge.kicad_pcb, cartridge.kicad_sch, host.kicad_sch]
2024-05-27 Fully route 5V signals.
    [cartridge.kicad_pcb, cartridge.kicad_sch]
2024-05-27 Attach control bus to MCU.
    [cartridge.kicad_pcb, cartridge.kicad_sch, host.kicad_sch]
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2024-06-20 Re-route CoCo bus with all 74-245s.
    [cartridge.kicad_pcb, cartridge.kicad_sch, host.kicad_sch]
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2024-06-25 Add a bunch of USB stuff.
    [cartridge.kicad_pcb, cartridge.kicad_sch]
2024-06-30 Finish USB power management.
    [cartridge.kicad_pcb, cartridge.kicad_sch, host.kicad_sch]
2024-07-06 Add 32 kHz crystal.
    [cartridge.kicad_pcb, cartridge.kicad_sch]
2024-07-10 Start designing cartridge case.
    [ChameleonCase.FCStd]
2024-07-10 Add screw posts to enclosure.
    [ChameleonCase.FCStd]
2024-07-10 Add bottom shell to enclosure.
    [ChameleonCase.FCStd]
2024-07-11 Re-model enclosure screw posts.
    [ChameleonCase.FCStd]
2024-07-11 Add shutter pocket to enclosure.
    [ChameleonCase.FCStd]
2024-08-06 Start re-modelling the enclosure.
    [ChameleonCase2.FCStd]
2024-08-06 Fix direction of top case lip.
    [ChameleonCase2.FCStd]
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2024-08-06 Remove old enclosure model.
    [ChameleonCase.FCStd]
2024-08-06 Rename new enclosure model.
    [ChameleonCase.FCStd, ChameleonCase2.FCStd]
2024-08-08 Add support ribs to top case and fix shutter clearance.
    [ChameleonCase.FCStd]
2024-08-08 Add inner fillets back to top shell.
    [ChameleonCase.FCStd]
2024-08-09 Re-model shell to fix fillets.
    [ChameleonCase.FCStd]
2024-08-11 Add modelled printing support for top case.
    [ChameleonCase.FCStd]
2024-09-06 Add a CR2016 battery holder.
    [ChameleonCase.FCStd, cartridge.kicad_pcb, cartridge.kicad_sch]
2024-09-19 Reroute around the battery holder.
    [cartridge.kicad_pcb]
2024-11-14 Roll back adding CR2016 battery.
    [cartridge.kicad_pcb, cartridge.kicad_sch]
2024-11-26 Start working on Li-Poly battery.
    [cartridge.kicad_pcb, cartridge.kicad_sch, power.kicad_sch]
2024-12-20 Add support block for top case, upgrade to FC 1.0.
    [ChameleonCase.FCStd]
2024-12-22 Add light pipe and fill for arrow.
    [ChameleonCase.FCStd]
2025-01-06 Add modeled support for sticker relief.
    [ChameleonCase.FCStd]
2025-01-06 Roll back adding Li-Poly battery.
    This reverts commit 081752ba55a88da4e16a76dc68d1f4d967b2094e.
    [cartridge.kicad_pcb, cartridge.kicad_sch, power.kicad_sch]
2025-01-27 Add clip recesses to top shell.
    [ChameleonCase.FCStd]
2025-01-27 Remove watch crystal and audio DAC.
    These can be implemented later; they're not needed
    for a first-gen prototype to determine whether the
    ESP32-S3 will even be able to bit-bang the bus.
    [cartridge.kicad_pcb, cartridge.kicad_sch, host.kicad_sch]
2025-01-27 Move USB connector outward 1mm.
    [cartridge.kicad_pcb]
2025-01-28 Adjust clearance on insets and clips.
    [ChameleonCase.FCStd]
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2025-01-31 Model clips on bottom shell.
    [ChameleonCase.FCStd]
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2025-07-21 Ensure all parts are available from DigiKey and JLCPCB.
    This switches the symbols and footprints to the more widely available
    parts sourced from DigiKey. Parts also have an LCSC catalog number,
    which may be the same part or a cheaper compatible clone.
    [cartridge.kicad_pcb, cartridge.kicad_sch, host.kicad_sch]
2025-07-22 Remove USB host bulk capacitor.
    I'm reasonably certain the bulk capacitor referred to by the USB 2.0
    spec is only actually required for multi-port hubs.
    [cartridge.kicad_pcb, cartridge.kicad_sch]
2025-07-22 Fix issues with ESP32-S3-WROOM-1U library footprint.
    [cartridge.kicad_pcb, cartridge.kicad_sch]
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

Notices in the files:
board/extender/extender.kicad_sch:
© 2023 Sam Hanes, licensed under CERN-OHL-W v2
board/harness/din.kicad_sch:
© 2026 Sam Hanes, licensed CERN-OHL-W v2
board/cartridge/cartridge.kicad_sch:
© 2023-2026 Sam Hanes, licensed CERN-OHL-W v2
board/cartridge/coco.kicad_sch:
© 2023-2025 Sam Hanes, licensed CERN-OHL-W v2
